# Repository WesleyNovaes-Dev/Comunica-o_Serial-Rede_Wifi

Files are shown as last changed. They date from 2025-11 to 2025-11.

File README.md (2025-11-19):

# Gateway IoT: Comunicação Serial/USB em Rede para Balanças 

> **Projeto de Conclusão de Curso - Engenharia da Computação (Facens)**
> **Autores:** Johanna Bernecker, Pedro Henrique Garcia Silveira, Wesley Davi Zanon Novaes.

  

Este projeto apresenta um **Gateway IoT de baixo custo** desenvolvido para conectar balanças industriais (interface RS-232/USB) à rede corporativa (Wi-Fi). O sistema utiliza um microcontrolador ESP32 para capturar dados de pesagem, filtrar redundâncias e transmiti-los via TCP para um servidor ou sistema ERP, eliminando a necessidade de apontamentos manuais.

---

## 📑 Índice

1. [Visão Geral e Objetivos](#-visão-geral-e-objetivos)
2. [Arquitetura de Hardware](#-arquitetura-de-hardware)
3. [Funcionamento do Sistema](#-funcionamento-do-sistema)
4. [Instalação e Configuração](#-instalação-e-configuração)
5. [Resultados e Performance](#-resultados-e-performance)
6. [Viabilidade Econômica](#-viabilidade-econômica)

---

## 🔭 Visão Geral e Objetivos

O objetivo principal é modernizar balanças legadas que possuem apenas interfaces locais (Serial DB9 ou USB), integrando-as à **Indústria 4.0** sem o alto custo de substituição do equipamento.

**Principais Funcionalidades:**
* **Conectividade Universal:** Suporte a redes WPA2-Pessoal e **WPA2-Enterprise** (Corporativo).
* **Configuração Web:** Interface embarcada (SoftAP) para configuração de Wi-Fi e IP (DHCP ou Estático).
* **Otimização de Dados:** Algoritmo *LineChangeDetector* que reduz o tráfego de rede em 90% ao enviar apenas alterações de peso.
* **Resiliência:** Reconexão automática em caso de falha de rede sem perda de pacotes.

---

## 🛠 Arquitetura de Hardware

O projeto foi validado utilizando a balança **Toledo Prix 9094 Plus** e o seguinte hardware:

| Componente | Função |
| :--- | :--- |
| **ESP32 DevKitC V4** | Núcleo de processamento e conectividade Wi-Fi. |
| **Módulo MAX3232** | Conversor de níveis de tensão RS232 (±12V) para TTL (3.3V). |
| **Fonte de Alimentação** | Fonte externa 5V/3.3V para estabilidade do circuito. |
| **Conector DB9** | Interface física com a balança. |

### Diagrama de Conexões (Pinout)

As conexões entre o módulo conversor e o ESP32 utilizam a porta `Serial2`:

| Pino ESP32 | Função | Conexão no MAX3232 |
| :--- | :--- | :--- |
| **GPIO 16 (RX2)** | Receber Dados (RX) | Pino TX (TTL) |
| **GPIO 17 (TX2)** | Transmitir Dados (TX) | Pino RX (TTL) |
| **GND** | Aterramento | GND |
| **VCC (3.3V)** | Alimentação | VCC |

---

## 🧠 Funcionamento do Sistema

O firmware opera em uma máquina de estados:

1.  **Inicialização:** Tenta conectar ao último Wi-Fi salvo.
2.  **Modo AP (Configuração):** Se falhar, cria a rede `ESP32_Config` (IP 192.168.4.1) para configuração via navegador.
3.  **Modo Operação:**
    * Lê a porta Serial RS-232.
    * Aplica o filtro de dados repetidos.
    * Abre um Servidor TCP na porta **9000**.
    * Transmite dados limpos para o backend (Node.js).

---

## ⚙️ Instalação e Configuração

### 1. Firmware (ESP32)
1.  Abra o projeto no **Arduino IDE**.
2.  Certifique-se de que as bibliotecas `WiFi.h`, `Preferences.h` e `WebServer.h` estão instaladas.
3.  Ajuste o *Baud Rate* da serial conforme sua balança (ex: 9600 ou 115200) no arquivo principal:
    ```cpp
    SerialRS232.begin(115200, SERIAL_8N1, RS232_RX, RS232_TX); //
    ```
4.  Compile e carregue na placa.

### 2. Configuração de Rede
1.  Conecte-se à rede Wi-Fi **ESP32_Config**.
2.  Acesse `http://192.168.4.1`.
3.  Configure o SSID, Senha e escolha entre **DHCP** ou **IP Estático**.
4.  O dispositivo reiniciará e mostrará o IP obtido no Monitor Serial.

### 3. Backend (Node.js)
Para capturar os dados no computador/servidor:
1.  Instale o Node.js.
2.  Configure o IP do ESP32 no script `coleta_de_dados.js`:
    ```javascript
    const BALANCA_IP = '10.128.32.8'; 
    const BALANCA_PORTA = 9000;
    ```
3.  Execute o script: `node coleta_de_dados.js`.
4.  Os dados serão salvos automaticamente no arquivo `pesagens.csv`.

---

## 📊 Resultados e Performance

### Otimização de Tráfego
O sistema implementa filtragem inteligente. A tabela abaixo (baseada nos testes do TCC) demonstra que dados repetidos (balança estável) não consomem banda de rede.

| Estado | Dado Bruto | Ação do Gateway | Resultado |
| :--- | :--- | :--- | :--- |
| Instável | `I00.005` | Envia | Dado registrado no servidor |
| Instável | `I00.035` | Envia | Dado registrado no servidor |
| **Estável** | `E00.060` | **Envia** | Dado registrado (Peso Final) |
| **Estável** | `E00.060` | **Filtra** | **Nenhum pacote enviado (Economia)** |

### Latência
A latência média medida entre a leitura do peso e o registro no servidor foi de **~48ms**, viabilizando aplicações em tempo real.

| Métrica | Valor Médio |
| :--- | :--- |
| Latência Média | 48.75 ms |
| Perda de Pacotes | 0% |
| Tempo máx. sem falhas | 3h contínuas |

---

## 💰 Viabilidade Econômica

Um dos maiores diferenciais do projeto é o custo reduzido em comparação com a modernização oferecida pelos fabricantes de balanças.

| Solução | Custo Estimado (R$) | Descrição |
| :--- | :--- | :--- |
| **Gateway IoT (Este Projeto)** | **R$ 120,68** | Solução flexível, código aberto e Wi-Fi. |
| Modernização Comercial (Ethernet) | R$ 1.990,10 | Kit proprietário do fabricante. |
| **Economia** | **~93%**  |

---
*Trabalho desenvolvido no Centro Universitário Facens, Sorocaba/SP - 2025.

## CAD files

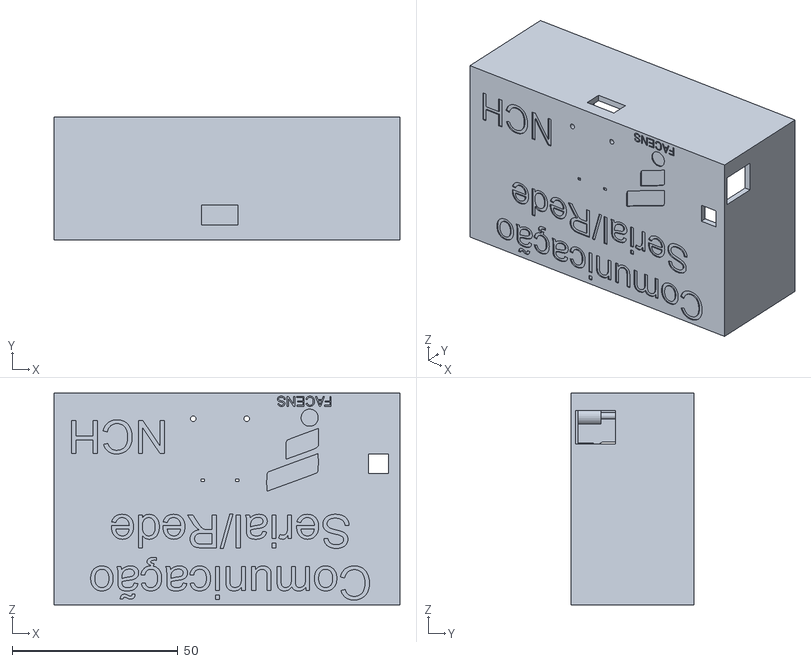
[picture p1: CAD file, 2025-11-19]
Case 3D/Case.stl
104.5 x 37.0 x 64.0

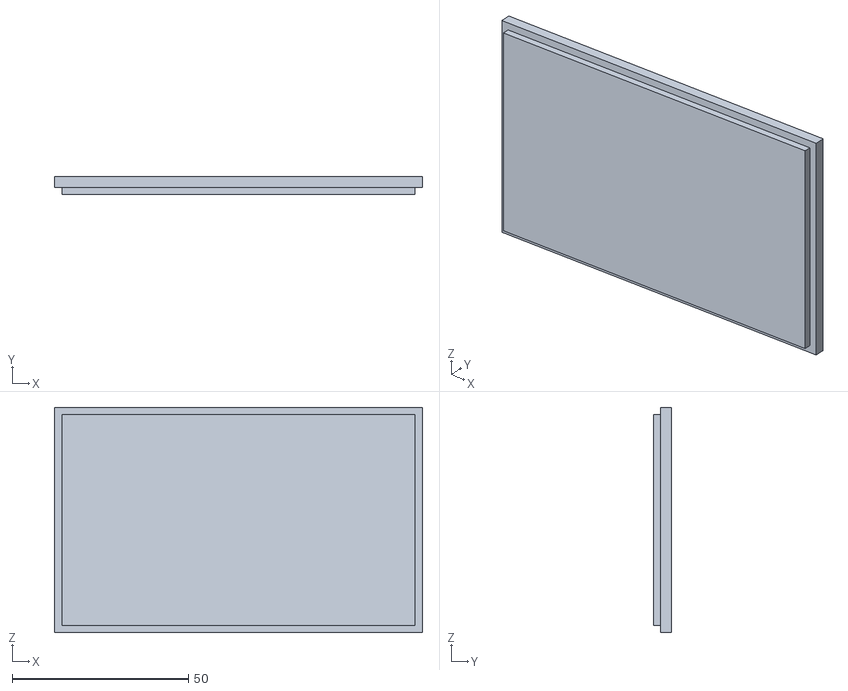
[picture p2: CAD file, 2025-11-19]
Case 3D/Tampa.stl
104.5 x 5.00 x 64.0

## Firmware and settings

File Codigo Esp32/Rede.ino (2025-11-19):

#include <WiFi.h>
#include <ESPmDNS.h>
#include <WiFiUdp.h>
#include <ArduinoOTA.h>
#include <Preferences.h>
#include "esp_eap_client.h"
#include <IPAddress.h>
#include <vector>
#include <stdarg.h>

// ==========================================================
// 1. DEFINIÇÕES E ESTRUTURAS
// ==========================================================
const int ledPin = 2;
#define RS232_TX 17
#define RS232_RX 16

// Configurações de Tempo
const long SOFTAP_GRACE_PERIOD_MS = 60000; 
const long SOFTAP_STARTUP_TIMEOUT_MS = 10000;

struct AuthClient {
    WiFiClient client;
    String ip;
};

// ==========================================================
// 2. OBJETOS GLOBAIS
// ==========================================================
HardwareSerial SerialRS232(2);
WiFiServer server(80);          
WiFiServer dataServer(9000); 
WiFiServer logServer(5000);  
Preferences prefs;

std::vector<AuthClient> dataClients;
std::vector<AuthClient> logClients;

// ==========================================================
// 3. VARIÁVEIS DE CONFIGURAÇÃO
// ==========================================================
String adminPassword = "123456";
String deviceHostname = "esp32-balanca";
long rs232Baud = 9600;
uint16_t dataPort = 9000;
uint16_t logPort = 5000;

// Variáveis de Rede
bool cancelConnect = false;
String lastSSID = "", lastPass = "", lastUser = "";
bool lastEnterprise = false;
bool lastUseStaticIP = false;
String lastStaticIP = "", lastSubnet = "", lastGateway = "", lastDns1 = "", lastDns2 = "";

// Variáveis Temporárias (Web)
bool connectionRequestFromWeb = false;
String webSsid, webPass, webUser;
bool webEnterprise, webUseStaticIP;
String webStaticIP, webSubnet, webGateway, webDns1, webDns2;

// Estado do Sistema
bool connectionJustSucceeded = false;
unsigned long connectionSuccessTime = 0;
bool isHandlingWebRequest = false;
unsigned long ledPreviousMillis = 0;
const long ledInterval = 500;
bool isRs232Active = false; 

// Controle de Peso
String lastSentWeight = ""; 
String currentWeightBuffer = "";
int dataSendFormat = 1; 

// --- Protótipos ---
void app_log(const char *format, ...);
void saveCredentials();
void startSoftAP();
void handleDataClient(); 
void broadcastWeightAndClientStatusToLog(String cleanWeight); 

// ==========================================================
// 4. SISTEMA DE LOG (Corrigido para incluir contagem e IP)
// ==========================================================

void app_log(const char *format, ...) {
    char buf[256];
    va_list args;
    va_start(args, format);
    vsnprintf(buf, sizeof(buf), format, args);
    va_end(args);
    Serial.print(buf);
    
    // REGRA DE LOG: Só envia o log completo se NÃO houver clientes de dados conectados.
    if (dataClients.empty()) {
        for (int i = logClients.size() - 1; i >= 0; i--) {
            if (logClients[i].client.connected()) {
                logClients[i].client.write((uint8_t*)buf, strlen(buf));
            } else {
                logClients[i].client.stop();
                logClients.erase(logClients.begin() + i);
            }
        }
    }
}

// CORREÇÃO: Implementação do log detalhado com contagem e IPs.
void broadcastWeightAndClientStatusToLog(String cleanWeight) {
    if (logClients.empty()) return;

    String dataClientList = "";
    for (const auto& client : dataClients) {
        if (!dataClientList.isEmpty()) dataClientList += ", ";
        dataClientList += client.ip;
    }
    if (dataClientList.isEmpty()) dataClientList = "Nenhum";

    String logClientList = "";
    for (const auto& client : logClients) {
        if (!logClientList.isEmpty()) logClientList += ", ";
        logClientList += client.ip;
    }
    
    // Log Detalhado (Peso + Contagem e IPs de Clientes)
    String logPayload = "[PESO]|" + cleanWeight + 
                        "|Clientes Dados (" + String(dataClients.size()) + "): " + dataClientList + 
                        "|Clientes Log (" + String(logClients.size()) + "): " + logClientList + 
                        "\n";
    
    for (int i = logClients.size() - 1; i >= 0; i--) {
        if (logClients[i].client.connected()) {
            logClients[i].client.write((const uint8_t*)logPayload.c_str(), logPayload.length());
        } else {
            logClients[i].client.stop();
            logClients.erase(logClients.begin() + i);
        }
    }
}


void handleLogClients() {
    if (logServer.hasClient()) {
        WiFiClient newClient = logServer.available();
        if (newClient) {
            AuthClient lc;
            lc.client = newClient;
            lc.ip = newClient.remoteIP().toString();
            logClients.push_back(lc);
            app_log("[LOG] Novo monitor IP: %s\n", lc.ip.c_str());
            app_log("[LOG] Clientes conectados: %d dados, %d log\n", dataClients.size(), logClients.size());
        }
    }

    // Limpa clientes de log desconectados
    for (int i = logClients.size() - 1; i >= 0; i--) {
        if (!logClients[i].client.connected()) {
            logClients[i].client.stop();
            logClients.erase(logClients.begin() + i);
            app_log("[LOG] Monitor desconectado: %s\n", logClients[i].ip.c_str());
        }
    }
}

// ==========================================================
// 5. GESTÃO DE REDE (WIFI)
// ==========================================================
void WiFiEvent(arduino_event_id_t event, arduino_event_info_t info){
    switch (event) {
        case ARDUINO_EVENT_WIFI_STA_START: app_log("[WIFI] Station Iniciado.\n"); break;
        case ARDUINO_EVENT_WIFI_STA_CONNECTED: app_log("[WIFI] Conectado ao AP.\n"); break;
        case ARDUINO_EVENT_WIFI_STA_DISCONNECTED: app_log("[WIFI] Desconectado! Razão: %d\n", info.wifi_sta_disconnected.reason); break;
        case ARDUINO_EVENT_WIFI_STA_GOT_IP: app_log("[IP] Atribuído: %s\n", WiFi.localIP().toString().c_str()); break;
        default: break;
    }
}

void configureStaticIP() {
    if (lastUseStaticIP && lastStaticIP.length() > 0) {
        IPAddress staticIP, gateway, subnet, dns1, dns2;
        if (staticIP.fromString(lastStaticIP) && gateway.fromString(lastGateway) && subnet.fromString(lastSubnet)) {
            dns1.fromString(lastDns1); dns2.fromString(lastDns2);
            app_log("[IP] Configurando IP Estático: %s\n", staticIP.toString().c_str());
            if (!WiFi.config(staticIP, gateway, subnet, dns1, dns2)) app_log("[ERRO] Falha IP Estático.\n");
        } else {
            app_log("[ERRO] Configuração IP inválida. Usando DHCP.\n");
            WiFi.config(IPAddress(0,0,0,0), IPAddress(0,0,0,0), IPAddress(0,0,0,0));
        }
    } else {
        app_log("[IP] DHCP Ativado.\n");
        WiFi.config(IPAddress(0,0,0,0), IPAddress(0,0,0,0), IPAddress(0,0,0,0));
    }
}

void startServices() {
    server.begin(); 
    dataServer.end(); dataServer.begin(dataPort);
    logServer.end(); logServer.begin(logPort);

    ArduinoOTA.setHostname(deviceHostname.c_str());
    ArduinoOTA.setPassword(adminPassword.c_str());
    ArduinoOTA.begin();
    app_log("[SISTEMA] Serviços Online. Portas - Web:80, Dados:%d, Log:%d\n", dataPort, logPort);
}

void connectNormal(String ssid, String pass) {
    cancelConnect = false;
    app_log("[CONEXAO] WPA2: %s\n", ssid.c_str());
    WiFi.disconnect(true); WiFi.mode(WIFI_AP_STA); configureStaticIP();
    WiFi.begin(ssid.c_str(), pass.c_str());
    int t = 0;
    while (WiFi.status() != WL_CONNECTED && t < 20 && !cancelConnect) { delay(1000); app_log("."); t++; }
    if (WiFi.status() == WL_CONNECTED) {
        // CORREÇÃO: Salva as credenciais/IPs usados
        lastSSID = ssid; lastPass = pass; lastEnterprise = false;
        lastUseStaticIP = webUseStaticIP; 
        if(lastUseStaticIP){ 
             lastStaticIP = webStaticIP; lastSubnet = webSubnet;
             lastGateway = webGateway; lastDns1 = webDns1; lastDns2 = webDns2;
        } else { 
             lastStaticIP = ""; lastSubnet = ""; lastGateway = ""; lastDns1 = ""; lastDns2 = "";
        }
        saveCredentials(); 
        connectionJustSucceeded = true; connectionSuccessTime = millis();
        startServices();
    } else { app_log("\n[FALHA] Conexão.\n"); }
}

void connectEnterprise(String ssid, String user, String pass) {
    cancelConnect = false;
    app_log("[CONEXAO] Enterprise: %s\n", ssid.c_str());
    WiFi.disconnect(true); WiFi.mode(WIFI_AP_STA); configureStaticIP();
    esp_eap_client_set_identity((uint8_t*)user.c_str(), user.length());
    esp_eap_client_set_username((uint8_t*)user.c_str(), user.length());
    esp_eap_client_set_password((uint8_t*)pass.c_str(), pass.length());
    esp_wifi_sta_enterprise_enable();
    WiFi.begin(ssid.c_str());
    int t = 0;
    while (WiFi.status() != WL_CONNECTED && t < 30 && !cancelConnect) { delay(1000); app_log("."); t++; }
    if (WiFi.status() == WL_CONNECTED) {
        // CORREÇÃO: Salva as credenciais/IPs usados
        lastSSID = ssid; lastUser = user; lastPass = pass; lastEnterprise = true;
        lastUseStaticIP = webUseStaticIP; 
        if(lastUseStaticIP){ 
             lastStaticIP = webStaticIP; lastSubnet = webSubnet;
             lastGateway = webGateway; lastDns1 = webDns1; lastDns2 = webDns2;
        } else { 
             lastStaticIP = ""; lastSubnet = ""; lastGateway = ""; lastDns1 = ""; lastDns2 = "";
        }
        saveCredentials(); 
        connectionJustSucceeded = true; connectionSuccessTime = millis();
        startServices();
    } else { app_log("\n[FALHA] Enterprise.\n"); startSoftAP(); }
}

// ==========================================================
// 6. PERSISTÊNCIA E HARDWARE
// ==========================================================
void saveCredentials() {
    prefs.begin("wifiCreds", false);
    prefs.putString("ssid", lastSSID); prefs.putString("pass", lastPass);
    prefs.putString("user", lastUser); prefs.putBool("enterprise", lastEnterprise);
    prefs.putBool("useStatic", lastUseStaticIP);
    if(lastUseStaticIP){
        prefs.putString("staticIP", lastStaticIP); prefs.putString("subnet", lastSubnet);
        prefs.putString("gateway", lastGateway); prefs.putString("dns1", lastDns1); 
        prefs.putString("dns2", lastDns2); 
    }
    prefs.end();
}

void loadCredentials() {
    prefs.begin("wifiCreds", true);
    lastSSID = prefs.getString("ssid", ""); lastPass = prefs.getString("pass", "");
    lastUser = prefs.getString("user", ""); lastEnterprise = prefs.getBool("enterprise", false);
    lastUseStaticIP = prefs.getBool("useStatic", false);
    lastStaticIP = prefs.getString("staticIP", ""); lastSubnet = prefs.getString("subnet", "");
    lastGateway = prefs.getString("gateway", ""); lastDns1 = prefs.getString("dns1", "");
    lastDns2 = prefs.getString("dns2", ""); 
    prefs.end();
    
    prefs.begin("sysConfig", true);
    adminPassword = prefs.getString("admPass", "123456");
    dataPort = prefs.getUShort("dPort", 9000);
    logPort = prefs.getUShort("lPort", 5000);
    rs232Baud = prefs.getLong("baud", 9600);
    dataSendFormat = prefs.getInt("dsf", 1); 
    prefs.end();
}

void clearCredentials(){ prefs.begin("wifiCreds", false); prefs.clear(); prefs.end(); lastSSID=""; }

void attemptReconnect() {
    if (lastSSID.length() > 0) {
        if (lastEnterprise) connectEnterprise(lastSSID, lastUser, lastPass);
        else connectNormal(lastSSID, lastPass);
    }
}

void checkSerialState() {
    if (WiFi.status() == WL_CONNECTED) {
        if (!isRs232Active) {
            SerialRS232.begin(rs232Baud, SERIAL_8N1, RS232_RX, RS232_TX);
            isRs232Active = true;
            app_log("[HARDWARE] Serial Ativada. Baud: %ld\n", rs232Baud);
        }
    } else {
        if (isRs232Active) {
            SerialRS232.end(); 
            isRs232Active = false;
            app_log("[HARDWARE] Serial Pausada (Modo Config).\n");
        }
    }
}

void startSoftAP() { 
    WiFi.mode(WIFI_AP_STA); 
    WiFi.softAP("ESP32_Config", "12345678"); 
    server.begin(); 
}

void stopSoftAP() { 
    if (WiFi.getMode() == WIFI_AP_STA) WiFi.softAPdisconnect(true); 
}

// ==========================================================
// 7. LÓGICA DE DADOS
// ==========================================================
String cleanWeightLine(const String &line) {
    String filtered = "";
    for (char c : line) { if (c >= 32 && c <= 126) filtered += c; }
    return filtered;
}

void broadcastData(String jsonPayload) {
    for (int i = dataClients.size() - 1; i >= 0; i--) {
        if (!dataClients[i].client.connected()) {
            dataClients[i].client.stop(); dataClients.erase(dataClients.begin() + i); continue;
        }
        size_t len = jsonPayload.length();
        dataClients[i].client.write((const uint8_t*)jsonPayload.c_str(), len);
        dataClients[i].client.write('\n'); 
    }
}

void handleDataClient() {
    if (dataServer.hasClient()) {
        WiFiClient c = dataServer.available();
        if (c) { 
            AuthClient ac; 
            ac.client = c; 
            ac.ip = c.remoteIP().toString(); 
            dataClients.push_back(ac);
            app_log("[DADOS] Novo cliente IP: %s\n", ac.ip.c_str());
        }
    }
    
    // Limpa clientes de dados desconectados
    for (int i = dataClients.size() - 1; i >= 0; i--) {
        if (!dataClients[i].client.connected()) {
            app_log("[DADOS] Cliente desconectado: %s\n", dataClients[i].ip.c_str());
            dataClients[i].client.stop(); 
            dataClients.erase(dataClients.begin() + i);
        }
    }

    if (isRs232Active && SerialRS232.available()) {
        while (SerialRS232.available()) {
            char c = SerialRS232.read();
            if (c == '\n' || c == '\r') {
                currentWeightBuffer.trim();
                if (currentWeightBuffer.length() > 0) {
                    String cw = cleanWeightLine(currentWeightBuffer);
                    if (cw != lastSentWeight) {
                        String payload;
                        if (dataSendFormat == 0) {
                            // FORMATO 0: JSON Completo (Pesagem e Latência)
                            payload = "{\"weight\":\"" + cw + "\",\"timestamp_ms\":" + String(millis()) + "}";
                        } else {
                            // FORMATO 1: Somente Pesagem (String Bruta Limpa)
                            payload = cw;
                        }

                        broadcastData(payload); 
                        lastSentWeight = cw;
                        
                        // LÓGICA DE LOG: Se há clientes de dados, envia o log condicional detalhado (Peso + Clientes)
                        if (!dataClients.empty()) {
                            broadcastWeightAndClientStatusToLog(cw);
                        } else {
                            // Se não há clientes de dados, usa o app_log padrão (que envia log detalhado)
                            app_log("[BALANCA] Peso: %s (Formato: %d)\n", cw.c_str(), dataSendFormat);
                        }
                    }
                }
                currentWeightBuffer = "";
            } else { currentWeightBuffer += c; }
        }
    }
}

// ==========================================================
// 8. SERVIDOR WEB - LAYOUT E FUNCIONALIDADES CORRIGIDOS
// ==========================================================
String urlDecode(String str) {
    String d = ""; char t[] = "0x00";
    for (unsigned int i = 0; i < str.length(); i++) {
        if (str[i] == '%') {
            if (i + 2 < str.length()) { t[2] = str[i+1]; t[3] = str[i+2]; d += (char)strtol(t, NULL, 16); i += 2; }
        } else if (str[i] == '+') d += ' '; else d += str[i];
    } return d;
}

String getParam(String req, String key) {
    String p = key + "="; int s = req.indexOf(p); if(s == -1) return "";
    s += p.length(); int e = req.indexOf('&', s);
    if(e == -1) e = req.indexOf(' ', s); if(e == -1) e = req.length();
    return urlDecode(req.substring(s, e));
}
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
void loop() {
    if (WiFi.status() == WL_CONNECTED) {
        digitalWrite(ledPin, HIGH);
        ArduinoOTA.handle();
        if (connectionJustSucceeded && (millis() - connectionSuccessTime > SOFTAP_GRACE_PERIOD_MS)) {
            stopSoftAP(); connectionJustSucceeded = false;
        }
    } else {
        if (millis() - ledPreviousMillis > 500) {
            ledPreviousMillis = millis(); digitalWrite(ledPin, !digitalRead(ledPin));
        }
    }

    checkSerialState();

    if (connectionRequestFromWeb) {
        connectionRequestFromWeb = false;
        
        stopSoftAP(); 
        if(isRs232Active) { SerialRS232.end(); isRs232Active = false; } 

        if (webEnterprise) connectEnterprise(webSsid, webUser, webPass);
        else connectNormal(webSsid, webPass);
    }

    WiFiClient client = server.accept();
    if (client) {
        isHandlingWebRequest = true;
        handleWebClient(client);
        client.stop();
        isHandlingWebRequest = false;
    }

    if (WiFi.status() == WL_CONNECTED && !isHandlingWebRequest) {
        handleLogClients();
        handleDataClient();
    }
}
